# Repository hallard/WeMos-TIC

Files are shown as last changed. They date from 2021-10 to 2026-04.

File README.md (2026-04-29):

# WeMos Teleinfo ESP8266/ESP32/S2/C3/S3 Shield

This shield is used to get French energy meter called Teleinfo data with any of the following boards:

- [WeMos D1 Mini][22] ESP8266
- [MH et Live ESP32 Mini Kit][23]
- [WeMos Mini S2][25] 
- [WeMos Mini C3][26]
- [WeMos Mini S3][27]

Take care the check wiring, because there is a lot of clone boards so please be sure to order the correct ones. If you want to be sure you can add it as option when you order this shield on [tindie][24], in bonus it will be flashed with tasmota teleinfo firmware.

Since price difference between ESP32 and ESP8266 boards is so small, to be able to use all future features such as Tamota with TLS, [Berry language](https://tasmota.github.io/docs/Berry/) or even tasmota new applications, I strongly suggest to use with ESP32 only. In the meanwhilen due to lack of ressources and Serial for debug (when using teleinfo), **no support for ESP8266 will be provided**. Of course it works fine, but I spent too much time each time to reproduce and track issues so I let it behind for now to focus on ESP32.  

**New in v1.2**

- Changed R3 by adjustable 2K resistor (trimer) to adjust Teleinfo signal sensitivity for Standard/Historique modes
- Added QWIIC/STEMA I2C classic connector
- Changed Blue Led resistor to decrease light intensity
- Placed easy cutting trace to disable Teleinfo Blue LED

**v1.1**

- Default RX goes to GPIO13 on ESP8266, GPIO23 on ESP32 (see other below)
- Reduded WS2812 RGB Led size, 4.3V powered, better brigtness 
- Added visual LED on teleinfo receive signal
- Reverted Signal 3V3 and GND on I2C connector, now "standard" looks more like that
- Replaced 2 GND pins by 5V and 3.3V to get more external power pins

**v1.0**

- Teleinfo Reader interface
- I2C Pullups placement
- Footprint for WS2812B RGB LED
- Classic I2C 128x64 OLED or sensors connector
- pad to solder components if needed to

WeMos provide three types of D1, [D1 Mini Lite][20], [D1 Mini][21] or [D1 Mini Pro][22] and also new [MH et Live ESP32 Mini Kit][23]

# Detailed Description

Look at the schematics for more informations, easy to understand. Wiring on the WeMos Teleinfo shield is as follow:

| Pin Function | ESP32 | ESP8266 | ESP32-S2 | ESP32-C3 | ESP32-S3 |
|  :--- |  :---:  |  :---:  |  :---: |  :---: |  :---: |
| Téléinfo Rx  |  GPIO23 | GPIO13  | GPIO11 | GPIO4 | GPIO11 |
| RGB Led |  GPIO18 | GPIO14  | GPIO7 | GPIO2 | GPIO12 |
| I2C SDA |  GPIO21 | GPIO4 | GPIO33 | GPIO8 | GPIO35 |
| I2C SCL |  GPIO22 | GPIO5 | GPIO35 | GPIO10 | GPIO36 |

You can change default Rx to `GPIO3` with solder pad `tic-rx`, but in this case, you need to cut the default trace and put solder between center pad and `IO3`, It's for advanced users, do it only if you need it and if you know what you are doing.

Default wiring on [ESP8266 Mini D1][21], [ESP32 Mini Dev board][23], [ESP32 S2 Mini][25] or [ESP32 C3 Mini][26] or [ESP32 S3 Mini][27]

| Pin Function | ESP32  | ESP8266 | ESP32-S2 | ESP32-C3 | ESP32-S3 |
|  :--- |  :---: |  :---:  |  :---: |  :---: |  :---: |
| On Board LED |  GPIO2 | GPIO16  | GPIO15 |  GPIO7 |  GPIO47  |
| On Board Button |  GPIO0 | GPIO16  |  GPIO0 |  GPIO9 |  GPIO0 |

Note : On ESP32-S3 the On Board LED is RGB WS2812 (same than on this shield) so to drive Shield LED use IO12 and to drive S3 Led use IO47

# Schematics

## V1.2
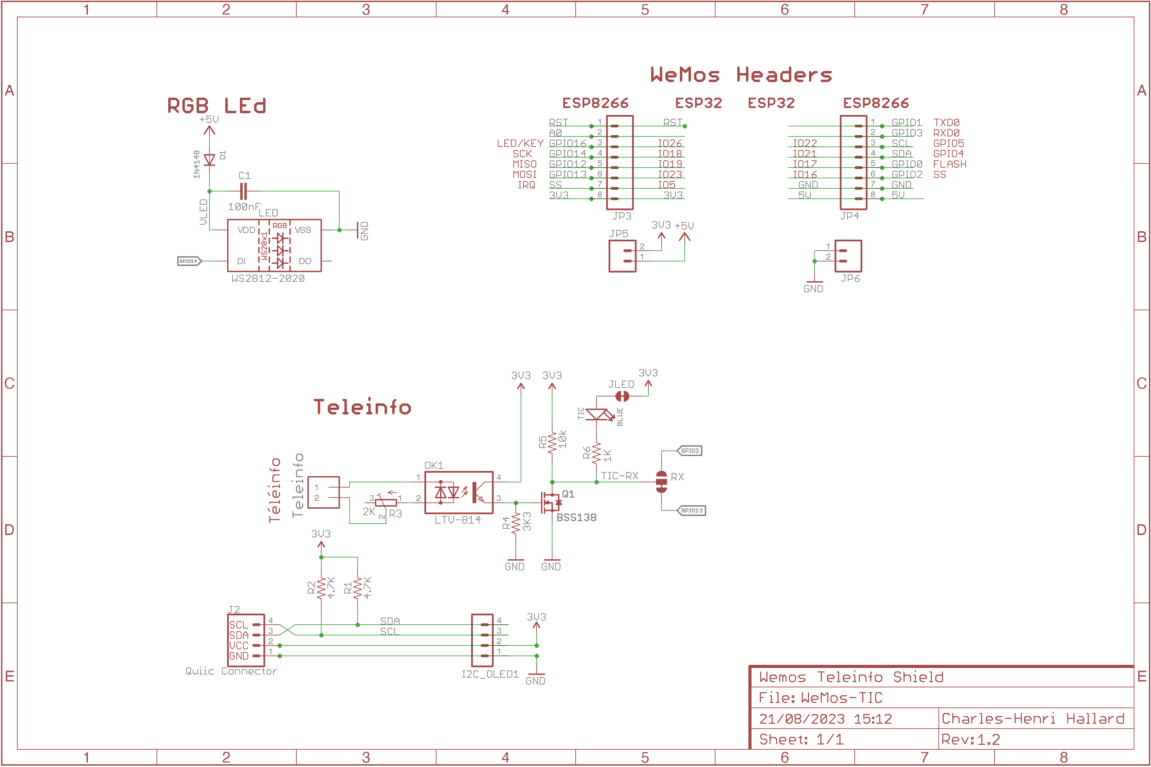
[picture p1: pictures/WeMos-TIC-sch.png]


## V1.1
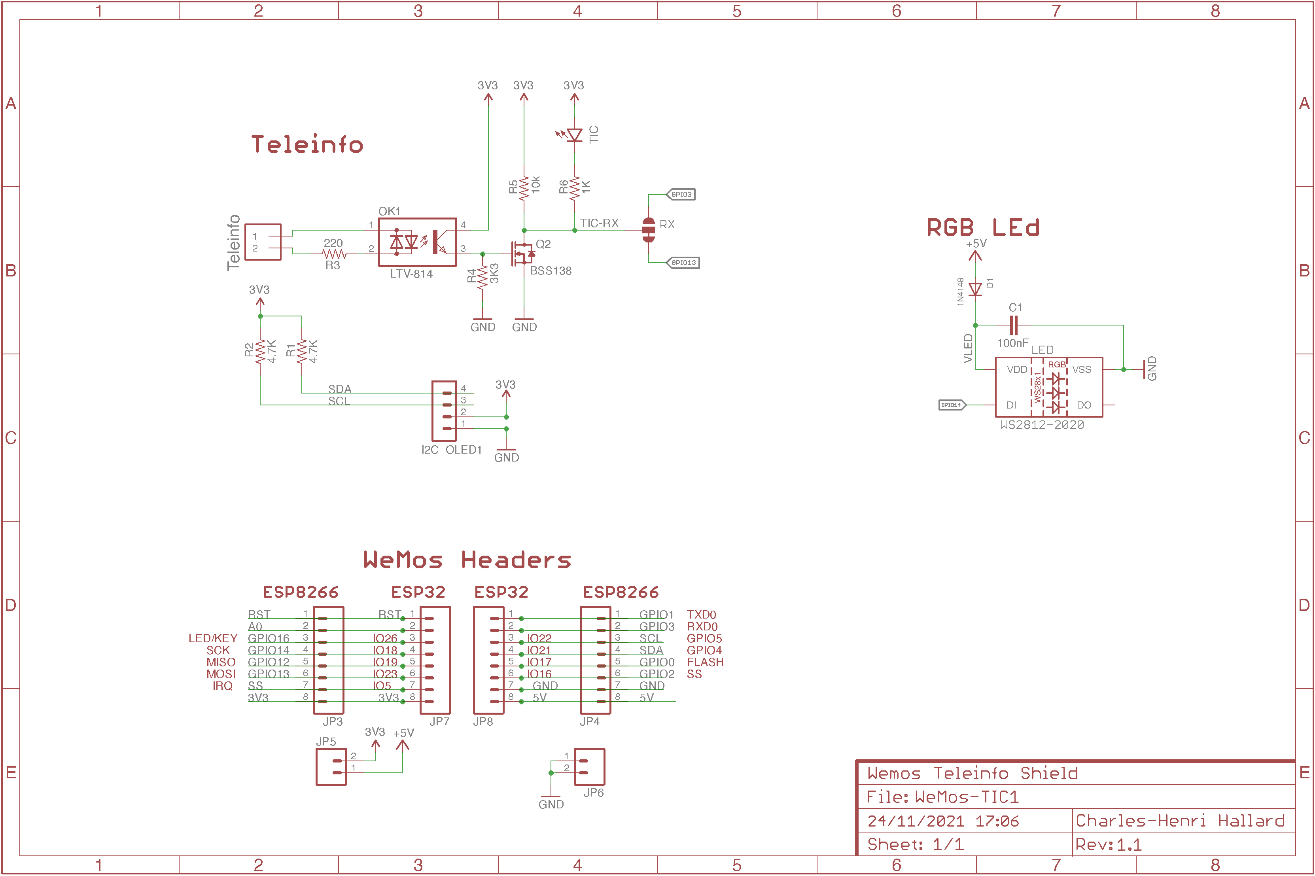
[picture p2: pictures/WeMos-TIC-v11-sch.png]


# Boards (V1.1)

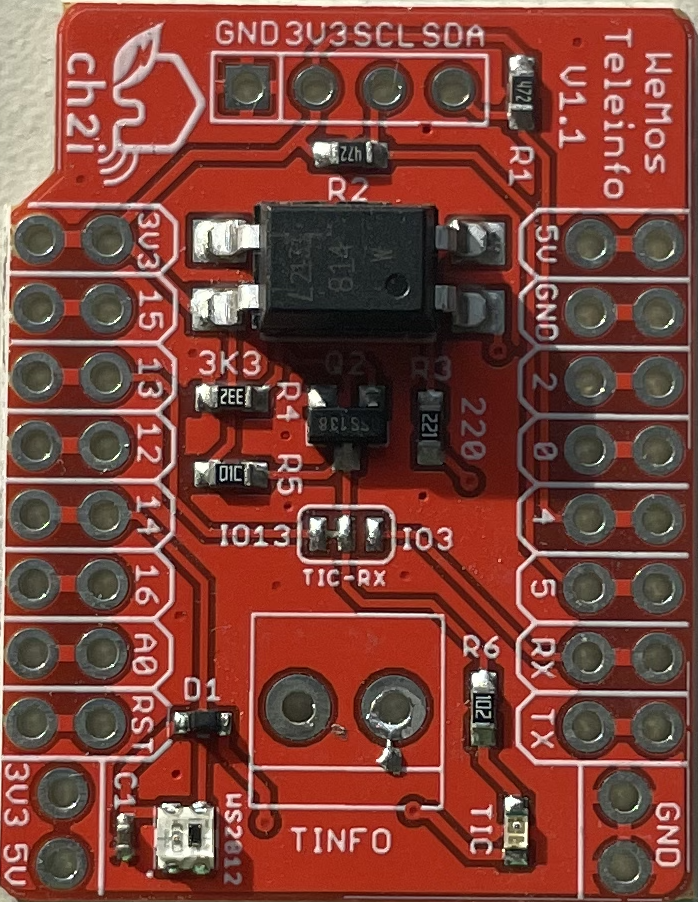
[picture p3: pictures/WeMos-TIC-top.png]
Top
&nbsp;
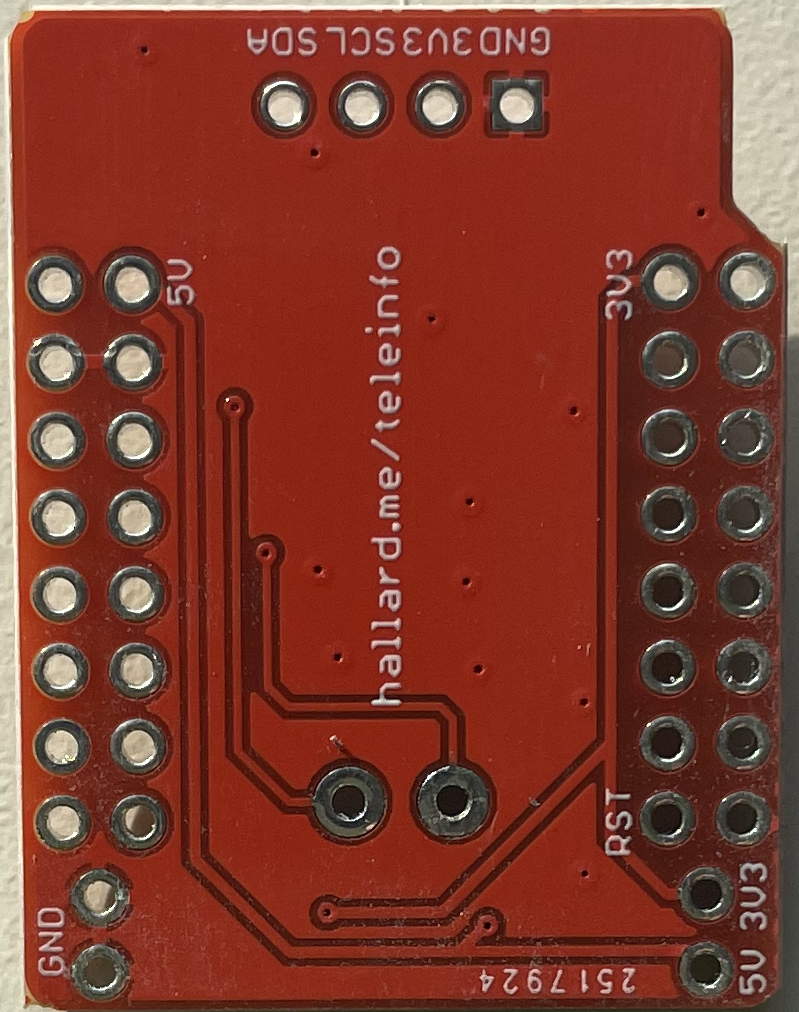
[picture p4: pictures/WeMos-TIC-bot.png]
Bottom


# Assembled boards

Here an example of boards connected with wiring on [ESP32 Mini Dev board][23]

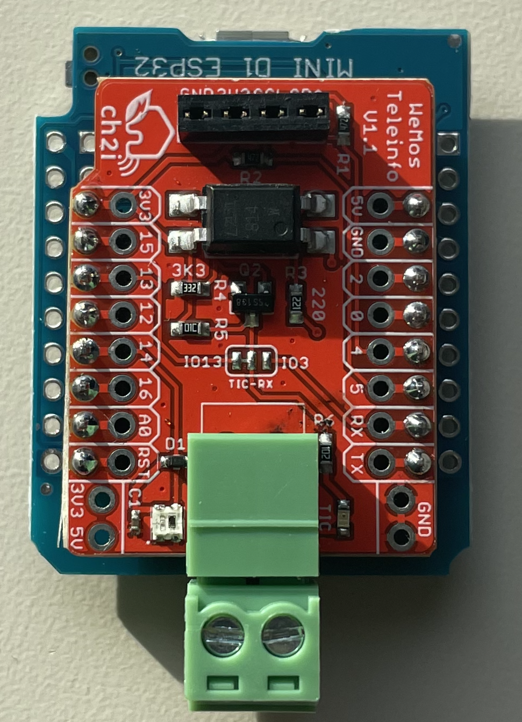
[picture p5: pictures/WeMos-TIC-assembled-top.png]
WeMos Teleinfo Assembled TOP
&nbsp;
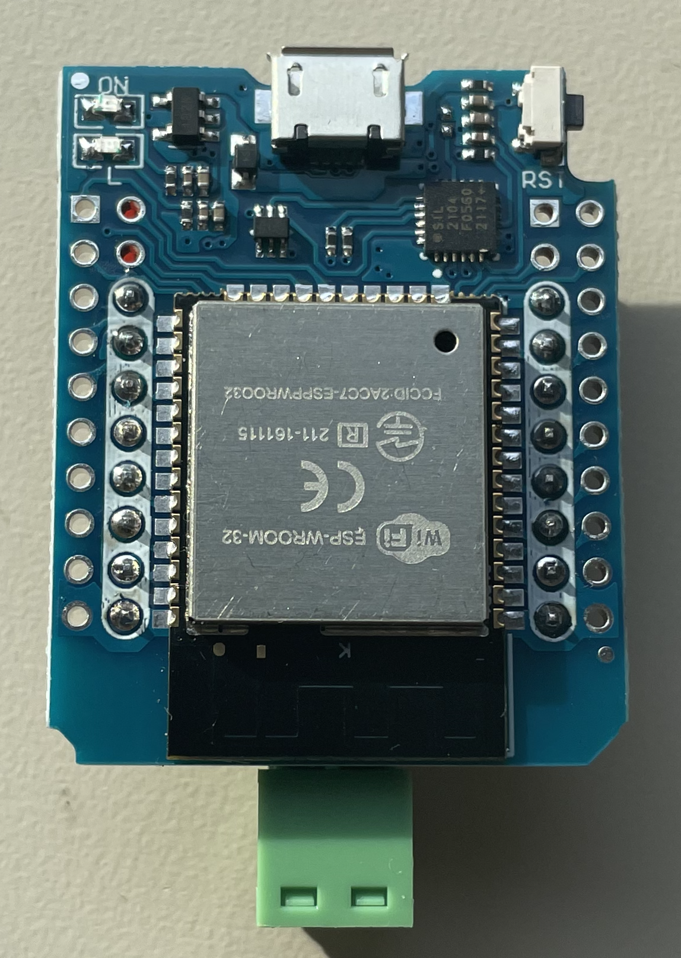
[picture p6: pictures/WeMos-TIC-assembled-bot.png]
WeMos Teleinfo Assembled Bottom


# Assembling

Nothing complicated, just use and solder headers. I suggest to use the small ones I sell with shield on Tindie, takes less place and you can either fix for life with just one part of the header soldered on both shield and ESP32.

Here boards connected to [ESP32 Mini Dev board][23]

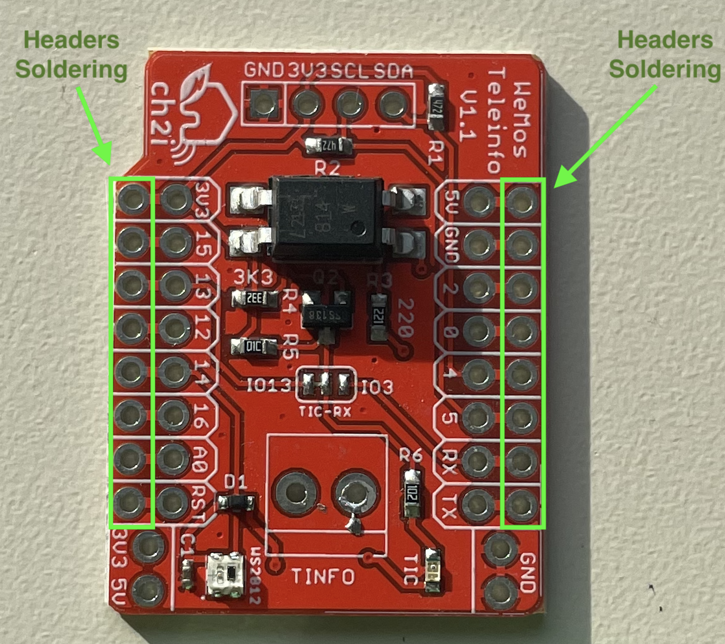
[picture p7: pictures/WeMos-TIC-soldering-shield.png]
&nbsp;
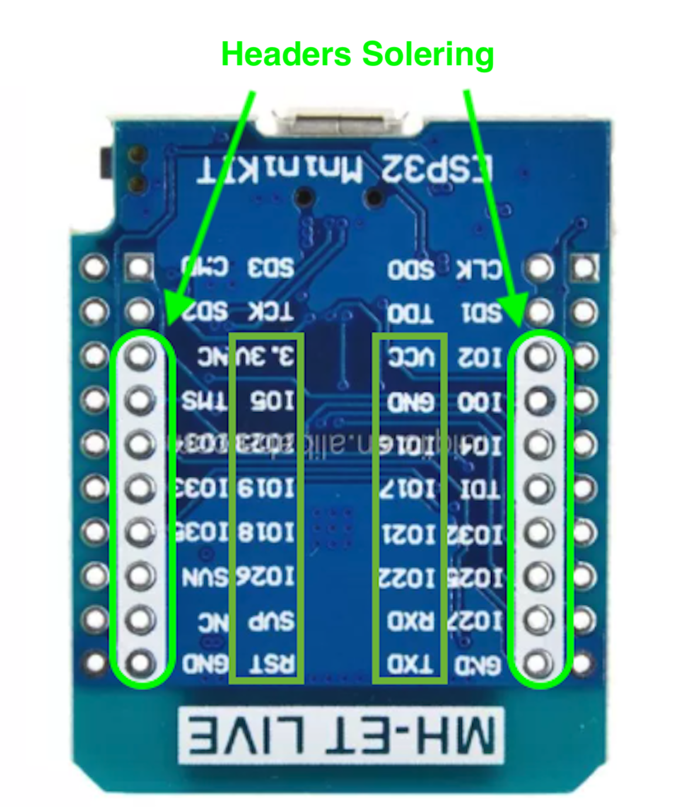
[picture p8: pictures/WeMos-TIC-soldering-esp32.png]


# 3D Print enclosure

@barbudor was kind enough to build and share awesome 3D enclosure for this shield. you can find `stl` file to print your own [here](3dprinted_enclosure). see pictures below

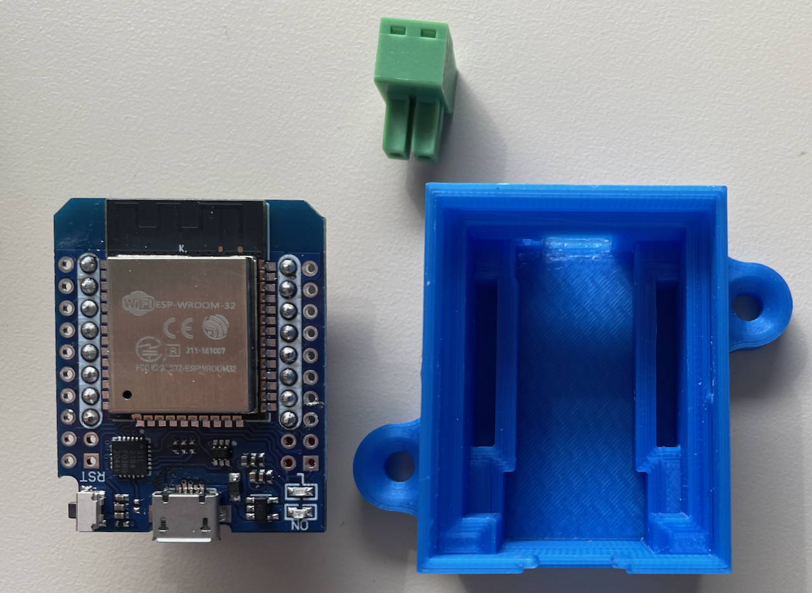
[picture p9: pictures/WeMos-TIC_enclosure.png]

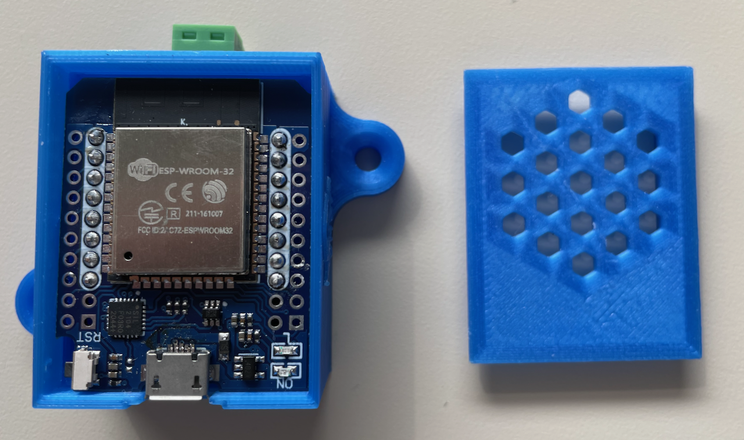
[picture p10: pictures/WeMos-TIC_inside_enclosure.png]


:warning: This enclosure fit perfelctly shield connected with WemMos ESP32 or D1 Mini ESP8266 **only when assembled with small headers**
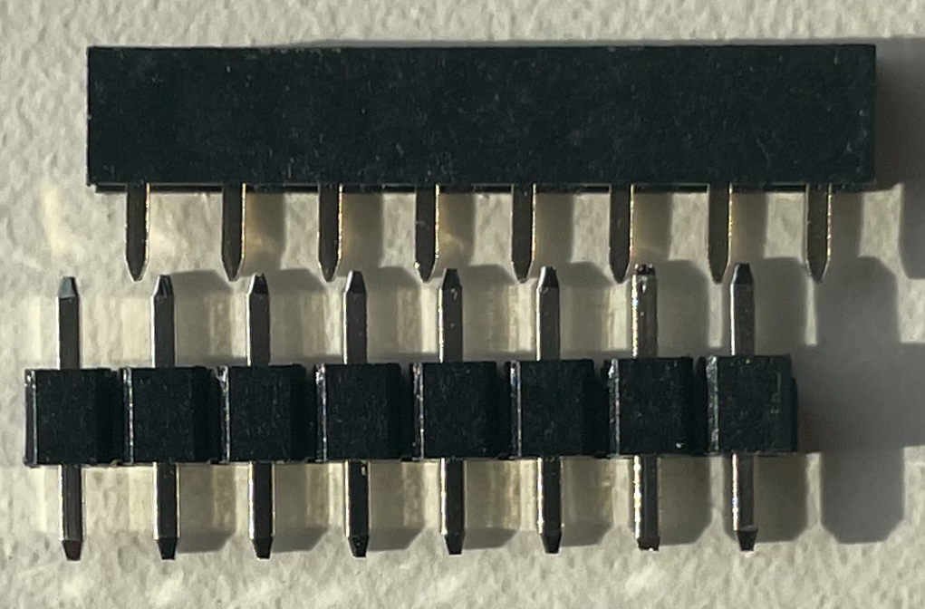
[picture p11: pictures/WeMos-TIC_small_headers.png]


You can add these headers when you order this shield on my [tindie store][24]

# Firmware 

You can write your own and use with [LibTeleinfo](https://github.com/hallard/LibTeleinfo) library I wrote if you want to get rid of driving teleinfo stuff (chekout some [examples](ttps://github.com/hallard/LibTeleinfo/tree/master/examples)).

## Tasmota

But I strongly suggest using amazing [Tasmota](https://tasmota.github.io/docs/) firmware, all is already done and well done.

Please check Teleinfo official tasmota [documentation](https://tasmota.github.io/docs/Teleinfo/) so see how to configure your device depending on smartmeter type and what options you need.

### Nicolas's builds

Nicolas @NicolasBernaerts has made awesome changes on Tasmota to be able to show graph of consumption, history and other great features such has:

- Ecowatt server to publish RTE Ecowatt signals
- TCP server to live stream teleinfo data
- FTP server to easily retrieve graph data

You can find more information on his dedicated [repo](https://github.com/NicolasBernaerts/tasmota/tree/master/teleinfo) and also ready made build for all compatible ESP boards.

### Unofficial builds

Teleinfo is not member of official Tasmota builds. So you need to build your own with `USE_TELEINFO` define. 
But Tasmota team agreed it's not simple to build for end users, and they now provide unofficial build that follow developement branch, this mean you always have an up to date build with latest code available. Of course we added Teleinfo (ESP8266 and ESP32) builds in this unofficial build process so you have nothing to install and compile/link (building). You can't go easier.

And as a cherry on the cake, easy flasher tools (web version and executable one) will present Teleinfo firmware so you are able to flash teleinfo firmware in less than 1 minute. You can check detail [here](https://github.com/Jason2866/Tasmota-specials) but here how to do that.

- Launch [Web Flasher here](https://jason2866.github.io/Tasmota-specials/) 
- Select Teleinfo (flash will auto detect if you need ESP8266 or ESP32 and will flash the correct one)
- Select Serial port, and click `install`

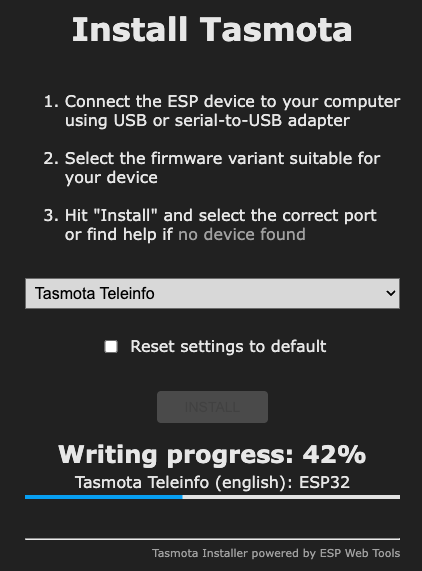
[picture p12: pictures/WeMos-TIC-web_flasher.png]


Once done something like that

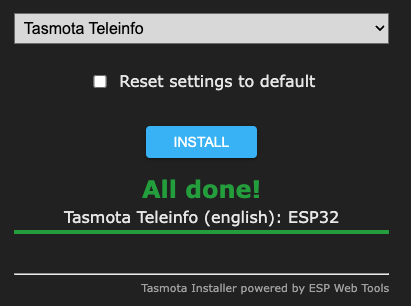
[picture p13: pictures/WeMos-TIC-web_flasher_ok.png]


After flashed, you should now see a new access point named `tasmota_aabbcc_xxxx` where you can connect to configure your WiFi for the device to connect on.

Alternatively, if you connect serial console and reset the device you should see Serial logs like that
```
00:00:00.003 HDW: ESP32-D0WDQ6 
00:00:00.037 UFS: FlashFS mounted with 308 kB free
00:00:00.109 CFG: Loaded from File, Count 12
00:00:00.124 QPC: Count 1
00:00:00.257 CFG: no '*.autoconf' file found
00:00:00.263 BRY: Berry initialized, RAM used=3620
00:00:00.282 BRY: no 'preinit.be'
00:00:00.291 Project tasmota - Tasmota Version 10.0.0.3(teleinfo)-2_0_1_1(2021-11-30T14:22:47)
00:00:00.379 BRY: no 'autoexec.be'
00:00:00.447 WIF: WifiManager active for 3 minutes
00:00:01.139 HTP: Web server active on tasmota-090F8C-3980 with IP address 192.168.4.1
00:00:06.827 QPC: Reset
```

If you want to deep into this process or just curious, you can check out it's [here](https://github.com/Jason2866/Tasmota-specials)

:memo: If you have some issues flashing with Web Flasher, do not hesitate to use another awesome tool [ESP Flasher](https://github.com/Jason2866/ESP_Flasher), with this one you can see exactly what's going on in case of issue because it has built in console. Usefull also after reboot of the device because console still active. This is the one I'm using day by day. In this case you need to download firmware to flash first [here](https://github.com/Jason2866/Tasmota-specials/tree/firmware/firmware/tasmota/other). Download firmware `tasmota-teleinfo`

You can take a look on `autoconf` [folder](https://github.com/tasmota/autoconf/tree/main/raw/esp32/Wemos_Teleinfo) to see some of init commands used on ESP32. For ESP8266 you can copy content of `autoexec.bat` and manually apply to you ESP8266 teleinfo.

:memo: Don't forget to reset Energy counters on first boot with console command `EnergyTotal 0` if you have erratic values. 

### I2C Display

You can add fancy I2C display (or even I2C sensors), take care of wiring of the display. They are not all usin the same order wiring the 4 pins on I2C connector. You need to use one with this order `GND VCC SDL SDA`. Since I2C VCC is conencted to 3.3V, your I2C device is compatible with 3.3V or 5V ones (They all have shifter since majorty of sensors works at 3.3V)

Then with tasmota you need to select correct one, in my example below it's an SHT1106 128x64 so config is (use only one time). Pleasy check Tasmota documentation for [display](https://tasmota.github.io/docs/Displays/) and associaed [commands](https://tasmota.github.io/docs/Commands/#displays).

```
DisplayMode 2
; 2 for SSD1306 and 7 for SH1106
DisplayModel 2
displaycols 21
displayrows 8
```

Don't forget to toggle ON on tasmota WEB UI since it's like a device. If not nothing will be displayed. You can also check the OLED presence using command `i2cScan` from console, something loke below sounds good, seen on `0x3c`

```
13:09:39.490 CMD: i2cscan
13:09:39.531 MQT: stat/tasmota_EF58A0/RESULT = {"I2CScan":"Device(s) found at 0x3c"}
```

And here is a picture of the whole working.

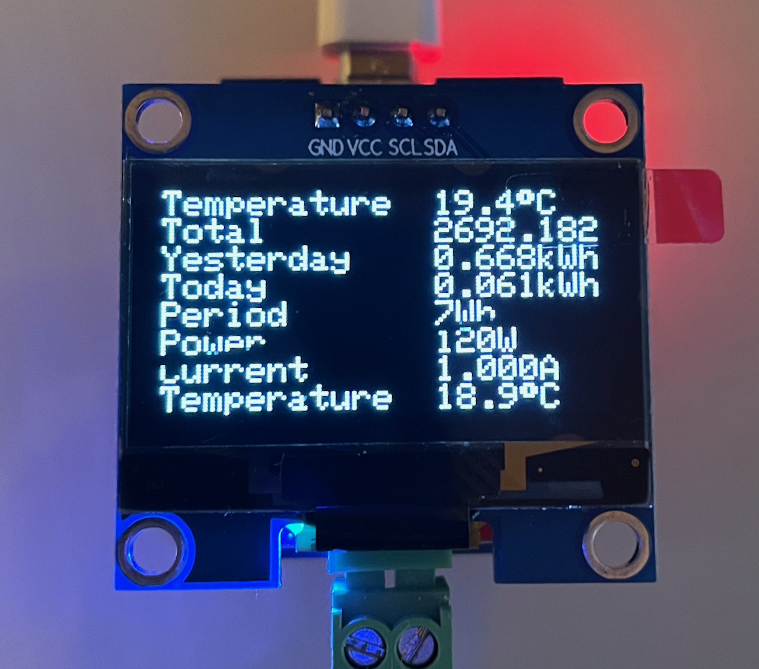
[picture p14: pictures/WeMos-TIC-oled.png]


### Autoconf (ESP32 Only)

Another awesome feature of Tasmota is the ability to download configuration profile, and guess what, we done it for this shield, just go to configuration option, select Autoconfig and then choose in the list `Wemos Teleinfo` and here you are, ne need to copy/paste template, it's done by autoconfig.
If you want to deep into this process or just curious, you can check out it's [here](https://github.com/tasmota/autoconf)

### Berry Scripting (ESP32 Only)

Now you can personalize code with [Berry language](https://tasmota.github.io/docs/Berry/). Check out some Berry samples [here](https://github.com/arendst/Tasmota/blob/development/tasmota/berry/examples/)

You can do that by going to Berry console from Tasmota WEB user interface.

#### Drive RGB LED depending on actual power

Here is a Berry example, goal is to follow real time consumption driving on board RGB Led depending on current Power consumption (low green then going to red when reaching maximum current of your contract)

```python
#-
# example of using Berry script to change the led color
# accordingly to power consumption
# using Denky or WeMos Teleinfo (French Teleinfo reader)
-#

#- define the global symbol for reference -#
runcolor = nil

def runcolor()
  var max_contrat = 30 # contrat 30A
  var i = energy.current
  #print(i)
  var red = tasmota.scale_uint(int(i), 0, max_contrat, 0, 255)
  var green = 255 - red
  var channels = [red, green, 0]
  light.set({"channels":channels, "bri":64, "power":true})
  tasmota.set_timer(2000, runcolor)
end

#- run animation -#
runcolor()
```

#### Send data to Emoncms with Berry (ESP32 only)

What's magic with Berry is the ability to do basic stuff with data, in this example we will intercept MQTT send message by Energy driver, do some calc and send data to Emoncms every 15 seconds and also to drive RGB Led from Green (low load) to Red (approach max subscription)

Modifiy API key with your, and copy paste the following code into Berry Console. Tst and validate if all is okay for you.

Once all is fine, you paste the code into a file named `autoexec.be` on the Tasmota Filesystem so it will be executed each time Tasmota device starting.

### Mode Historique (contrat heures creuses)

```python
import json

var api_url = "https://emoncms.org/input/post"
var api_key = "YOUR_EMON_API_WRITE_KEY"
var node_name = "NODE_NAME"
var post_every = 15000 # post evert 15 seconds
var payload = {}

def send_emoncms()
  # Convert JSON object to string 
  var obj_json = json.dump(payload)

  # Create URL to call
  var param="?fulljson="+obj_json + "&node="+node_name + "&apikey="+api_key 
  # Post Data to EMONCMS
  var cl = webclient()
  cl.begin( api_url + param)
  var r =  cl.GET()
  tasmota.set_timer(post_every, send_emoncms)
end

def setcolor(iinst, isousc)
  var red = tasmota.scale_uint(iinst, 0, isousc, 0, 255)
  var green = 255 - red
  var channels = [red, green, 0]
  light.set({"channels":channels, "bri":64, "power":true})
end

# set global payload the field we need
def rule_tic(value, trigger)
  # Got Heures Creuses contract so I will calculate total consumption
  # adding Heures Creuses (HCHC) + Heures Pleines (HCHP) and create new value for emoncms 
  # Change label depending on name for your contract type
  var htot = value['HCHP'] + value['HCHC'] # mode historique
  # Create new value HTOT converted to kWH
  payload['HTOT'] = htot / 1000.0
  # Calculate current percent Load 
  var iinst = value['IINST']  # mode historique
  var isousc= value['ISOUSC'] # mode historique

  if iinst != nil && isousc != nil 
    # Drive RGB LED
    setcolor(iinst, isousc)
    if isousc > 0
      load = 100 * iinst / isousc
      payload['LOAD'] = load
    end
  end

  # Set values we need to send to emoncms
  payload['ADCO']  = value['ADCO']
  payload['HCHP']  = value['HCHP']
  payload['HCHC']  = value['HCHC']
  payload['ISOUSC']= isousc
  payload['PAPP']  = value['PAPP']
  payload['IINST'] = iinst

end

def start()
  # Callback on each frame interception
  tasmota.add_rule("TIC",rule_tic)
  # fire 1st post in 5s 
  tasmota.set_timer(5000, send_emoncms)
end

# delay start to have time to get full frame
tasmota.set_timer(10000, start)

```

### Mode Standard (contrat heures creuses)

```python
import json

var api_url = "https://emoncms.org/input/post"
var api_key = "YOUR_EMON_API_WRITE_KEY"
var node_name = "NODE_NAME"
var post_every = 15000 # post evert 15 seconds
var payload = {}

def send_emoncms()
  # Convert JSON object to string 
  var obj_json = json.dump(payload)

  # Create URL to call
  var param="?fulljson="+obj_json + "&node="+node_name + "&apikey="+api_key 
  # Post Data to EMONCMS
  var cl = webclient()
  cl.begin( api_url + param)
  var r =  cl.GET()
  tasmota.set_timer(post_every, send_emoncms)
end

def setcolor(iinst, isousc)
  var red = tasmota.scale_uint(iinst, 0, isousc, 0, 255)
  var green = 255 - red
  var channels = [red, green, 0]
  light.set({"channels":channels, "bri":64, "power":true})
end

# set global payload the field we need
def rule_tic(value, trigger)
  # Got Heures Creuses contract so I will calculate total consumption
  # Calculate current percent Load 
  var iinst = value['IRMS1']  
  var isousc= value['PREF']*5 

  if iinst != nil && isousc != nil 
    # Drive RGB LED
    setcolor(iinst, isousc)
    if isousc > 0
      load = 100 * iinst / isousc
      payload['LOAD'] = load
    end
  end

  # Here I keep name of historique mode
  payload['ADCO']  = value['ADSC']
  payload['HTOT']  = value['EAST'] / 1000 # I need kWh
  payload['HCHP']  = value['EASF01']
  payload['HCHC']  = value['EASF02']
  payload['ISOUSC']= isousc
  payload['PAPP']  = value['SINSTS']
  payload['IINST'] = iinst

end

def start()
  # Callback on each frame interception
  tasmota.add_rule("TIC",rule_tic)
  # fire 1st post in 5s 
  tasmota.set_timer(5000, send_emoncms)
end

# delay start to have time to get full frame
tasmota.set_timer(10000, start)

```

### Tasmota templates

Use the following templates depending on version of shield and ESP board (but I strongly suggest using autoconf if you have a ESP32 board)

#### Shield Version 1.1

ESP8266
```
{"NAME":"Wemos Teleinfo","GPIO":[1,1,1,1,640,608,1,1,1,5152,1376,1,1,1],"FLAG":0,"BASE":18}
```

ESP32
```
{"NAME":"Wemos Teleinfo","GPIO":[1,1,1,1,1,1,1,1,1,1,1,1,1,1,1376,1,1,640,608,5632,1,1,0,1,0,0,0,1,1,1,1,1,1,1,1,1],"FLAG":0,"BASE":1}
```

ESP32-S2-Mini
```
{"NAME":"Wemos Teleinfo","GPIO":[1,1,1,1,1,1,1,1376,1,1,1,5632,1,1,1,1,1,1,1,5632,1,1,640,1,608,1,0,1,1,1,1,1,1,1,1,1],"FLAG":0,"BASE":1}
```

ESP32-C3-Mini
```
{"NAME":"Wemos Teleinfo","GPIO":[1,1,1376,1,5632,1,1,288,640,1,608,1,1,1,1376,1,1,640,1,0,1,1],"FLAG":0,"BASE":1}
```

ESP32-S3-Mini
```
{"NAME":"Wemos Teleinfo","GPIO":[32,1,1,0,0,1,1,1,1,1,1,5632,1376,1,0,1,1,1,1,1,1,1,0,0,640,608,0,0,0,0,0,0,1,1,0,0,1377,0],"FLAG":0,"BASE":1}
```

#### Shield Version 1.0

Teleinfo RX is on GPIO3 for each board

ESP8266
```
{"NAME":"TICShield","GPIO":[1,1,1,5152,640,608,1,1,1,1,1376,1,1,1],"FLAG":0,"BASE":18}
```

ESP32
```
{"NAME":"TICShield32","GPIO":[1,1,1,5632,1,1,1,1,1,1,1,1,1,1,1376,1,1,640,608,1,1,1,0,1,0,0,0,1,1,1,1,1,1,1,1,1],"FLAG":0,"BASE":1}
```

# Support and discussion

If you have any issue or just want to discuss on this project, please use community [forum](https://community.ch2i.eu/category/19/wemos-teleinfo)

# License

   

This work is licensed under a [Creative Commons Attribution-NonCommercial-ShareAlike 4.0 International License](https://creativecommons.org/licenses/by-nc-sa/4.0/)    
If you want to do commercial stuff with this project, please contact [CH2i company](https://ch2i.eu/en#support) so we can organize an simple agreement.

# Lazy building your own? 

You can order this shield fully assembled with some extra on [tindie][24] or on [Lectronz](https://lectronz.com/products/wemos-tic).

European customers may prefer ordering on Lectronz, which offers additional payment methods and pricing in Euros.





# Misc

See news and other projects on my [blog][2] 
 
[2]: https://hallard.me

[20]: https://www.wemos.cc/en/latest/d1/d1_mini_lite.html
[21]: https://www.wemos.cc/en/latest/d1/d1_mini.html
[22]: https://www.smart-prototyping.com/Mini-D1-PRO-Development-Board-ESP8266-4M-16M
[23]: https://www.az-delivery.de/fr/products/esp32-d1-mini
[24]: https://www.tindie.com/products/25467/
[25]: https://www.wemos.cc/en/latest/s2/s2_mini.html
[26]: https://www.wemos.cc/en/latest/c3/c3_mini.html
[27]: https://www.wemos.cc/en/latest/s3/s3_mini.html

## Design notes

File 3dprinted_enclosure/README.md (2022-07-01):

# 3D Printed Enclosure for WeMos-TIC
by Barbudor
Designed with TinkerCAD

v1.1 : available here https://www.tinkercad.com/things/gjrSG7AgKoE-mini-d1-esp32-teleinfo-v11

Tested with mini-D1 ESP32 and D1 Mini ESP8266.

:warning: This enclosure perfectly fits Teleinfo shield mounted below a WeMos ESP32 or D1 Mini ESP8266 **only when assembled with small headers**


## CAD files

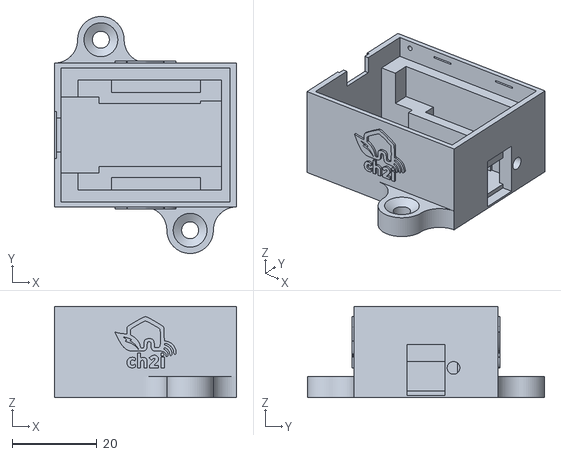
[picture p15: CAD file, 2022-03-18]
3dprinted_enclosure/enclosure.stl
43.0 x 56.0 x 21.5

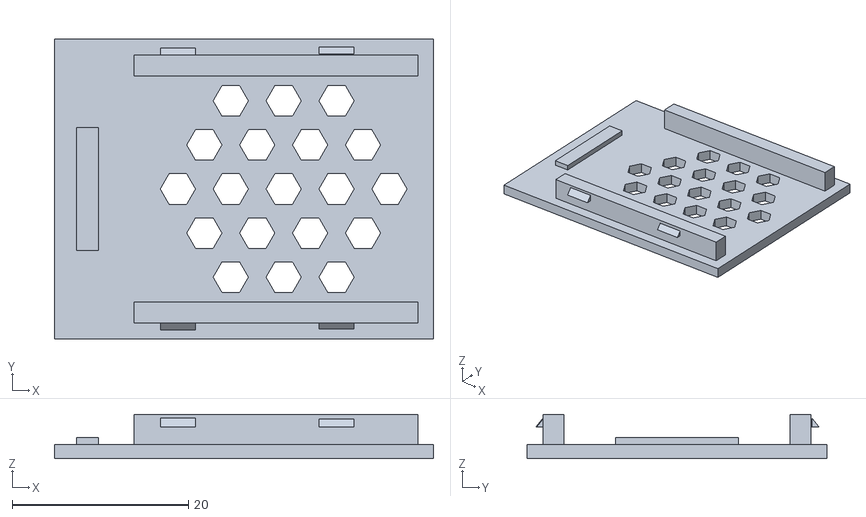
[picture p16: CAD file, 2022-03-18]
3dprinted_enclosure/lid.stl
43.0 x 34.0 x 5.00

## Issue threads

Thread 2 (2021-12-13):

Erreur N° GPIO

remycrochon, 2021-12-13:
Bonjour
Dans le tableau le numéro de pin du RX du ESP32 est GPIO23 et non GPIO32
Salutations

hallard, 2021-12-14:
Correct, merci du retour c'est fixé

Closed 2021-12-14.

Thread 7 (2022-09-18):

soldering schema for WeMos Mini S2 ?

mcarbonneaux, 2022-09-18:
I've buy your shield and i whant to be sure how to connect it.

How to solder your adapter to the mini s2 ? use external or internal line ?
You have made the schematique for the esp32 mini dev, but not for the other one...

her : https://github.com/hallard/WeMos-TIC#assembling
When see you table her : https://github.com/hallard/WeMos-TIC#detailed-description

If I understand all pine of your shield are linked for each couple of external/internal line.

If i sold the exterior line of your shield to the external line of S2 like that :

| Shield Pin | ESP32-S2 |
|  :---        |    :---:   |
| GND  | GND |
| 5V | VBUS |
| 3V3 | 3V3 |

And normaly the pin function table while be :

| Shield Pin Function | ESP32-S2 |
|  :---        |    :---:   |
| Téléinfo Rx  | <**GPIO37**> |
| RGB Led (14)     | GPIO07 |
| I2C SDA (4)     | GPIO33 |
| I2C SDL  (5)    | GPIO35 |

LED/SDA/SDL are corresponding but RX are not corresponding to the GPIO of your table (GPIO11 in your table and GPIO37 on the corresponding pin on S2).

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

hallard, 2022-09-20:
If you look at the schematic of the shield (which is the same for all module), Teleinfo RX is connected to `GPIO13` (to leave RX/TX is for serial console) so it's `GPIO11` on S2 and all magic match :-)

Blank text on the PCB (silk) is the one for ESP8266 that may, I must admit do some confusion, but that's the price of compatibility and this is why I put mapping table on the readme.

mcarbonneaux, 2022-09-21:
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&nbsp;
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&nbsp;
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&nbsp;
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&nbsp;

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

hallard, 2022-09-21:
Thanks for sharing

Closed 2022-09-20.

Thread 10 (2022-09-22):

Le total energy est negatif

maelremrem, 2022-09-22:
Apres avoir attendu 24h,
Le total energy est négatif
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
J'ai aussi un soucis coté remontée d'info sur HomeAssistant, je peux remonter que le total énergétique et pas la consommation du jour
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
J'ai bien basculé en mode standard car j'ai un linky
Si vous avez des pistes
(Merci pour le PCB, vraiment super propre mais il ne rentre pas dans le STL fourni si on utilise un écran oled, je vais redesign un modèle 3D pour ça)

hallard, 2023-02-27:
peut-on clôturer cette issue ?

Closed 2024-01-11.

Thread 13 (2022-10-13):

Is is suitable for running on battery? (Wemos S2)

Donokami, 2022-10-13:
Hey,
And thanks for the project.
Before buying a WeMos-TIC shield, I was asking myself : what is the power consumption of the ESP32 with the WeMos-TIC board and the project running?
Would it be suitable for running the ESP on a battery? I don't have a modular socket on my electric panel, nor any socket around it :/

hallard, 2022-10-28:
Interesting I did not measured but since it does not sleep and has WiFi at least 100mA so depending on battery capacity should not go above few days.

Closed 2023-02-27.

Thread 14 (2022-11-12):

Portage vers Micropython

mdaeron, 2022-11-12:
Bonjour, merci pour ce projet !

Je suis un grand fan du Wemos S2 Mini que j'utilise sous Micropython pour pas mal de projets. J'aimerais acheter ce module et écrire moi-même (sous license libre évidemment) le code permettant de lire/sauvegarder/transmettre les valeurs de consommation. J'ai un peu regardé ici mais pour je n'ai pas encore compris si le code "habituel" (Tasmota Téléinfo ?) est open-source, et si oui où on peut le trouver.

hallard, 2022-11-12:
Le mieux (et le plus simple) et peut être de prendre le code de la librairie [LibTeleinfo](https://github.com/hallard/LibTeleinfo) (celle ci est incluse dans tasmota)

mdaeron, 2022-11-12:
Merci ! Du coup je viens d'en commander un sur Tindie. Beau projet bien ficelé, merci aussi pour les infos sur le blog.

Closed 2022-11-12.

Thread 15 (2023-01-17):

Wemos-Teleinfo & ESPHome: "bad crc" and "no group found" errors

tomav, 2023-01-17:
Hi @hallard, thanks for the wemos teleinfo board, I got mine from Tindie.
It works but I got these errors:

```
[23:12:12][E][teleinfo:133]: No group found
[23:12:16][D][sensor:127]: 'WiFi Signal dB': Sending state -61.00000 dBm with 0 decimals of accuracy
[23:12:43][E][teleinfo:038]: bad crc: got 60 except 56
[23:12:43][E][teleinfo:038]: bad crc: got 60 except 50
[23:12:43][D][sensor:127]: 'Linky Index': Sending state 35917.92578 kWh with 0 decimals of accuracy
[23:12:43][E][teleinfo:038]: bad crc: got 34 except 41
[23:12:43][E][teleinfo:168]: Invalid value for tag EASF02
[23:12:43][E][teleinfo:038]: bad crc: got 41 except 72
[23:12:43][E][teleinfo:038]: bad crc: got 41 except 35
[23:12:43][E][teleinfo:038]: bad crc: got 32 except 88
[23:12:43][E][teleinfo:038]: bad crc: got 32 except 95
[23:12:43][D][sensor:127]: 'Linky Puissance Souscrite': Sending state 12000.00000 VA with 0 decimals of accuracy
[23:12:43][D][sensor:127]: 'Linky Puissance Apparente': Sending state 2466.00000 VA with 0 decimals of accuracy
[23:12:43][E][teleinfo:038]: bad crc: got 94 except 84
[23:12:43][E][teleinfo:038]: bad crc: got 24 except 77
[23:12:43][E][teleinfo:038]: bad crc: got 60 except 86
[23:12:43][E][teleinfo:038]: bad crc: got 57 except 32
[23:12:55][D][sensor:127]: 'Uptime': Sending state 1532.19702 s with 0 decimals of accuracy
[23:13:16][D][sensor:127]: 'WiFi Signal dB': Sending state -61.00000 dBm with 0 decimals of accuracy
[23:13:43][E][teleinfo:038]: bad crc: got 60 except 87
[23:13:43][D][sensor:127]: 'Linky Index': Sending state 35917.97656 kWh with 0 decimals of accuracy
[23:13:43][E][teleinfo:038]: bad crc: got 36 except 57
[23:13:43][E][teleinfo:038]: bad crc: got 36 except 95
[23:13:43][E][teleinfo:038]: bad crc: got 41 except 77
[23:13:43][E][teleinfo:038]: bad crc: got 41 except 40
[23:13:43][E][teleinfo:038]: bad crc: got 32 except 87
[23:13:43][E][teleinfo:038]: bad crc: got 32 except 33
[23:13:43][D][sensor:127]: 'Linky Puissance Apparente': Sending state 2957.00000 VA with 0 decimals of accuracy
[23:13:43][E][teleinfo:038]: bad crc: got 94 except 89
[23:13:43][E][teleinfo:038]: bad crc: got 94 except 49
[23:13:55][D][sensor:127]: 'Uptime': Sending state 1592.19702 s with 0 decimals of accuracy
```

Same in historical or standard mode.
I use ESPHome, with an ESP32 (lolin s2 mini).

Here's my config, nothing too fancy.

```
uart:
  id: uart_a
  rx_pin: GPIO11
  baud_rate: 9600 # historical => 1200 / standard => 9600
  parity: EVEN
  data_bits: 7

teleinfo:
  id: myteleinfo
  uart_id: uart_a
  update_interval: 30s
  historical_mode: false # set to false when standard mode enabled

#### STANDARD

 # Energie Active soutirée totale
  - platform: teleinfo
    id: hc_hp
    tag_name: "EAST"
    name: "Linky Index"
    unit_of_measurement: "kWh"
    icon: mdi:flash
    teleinfo_id: myteleinfo
    device_class: "energy"
    state_class: "total_increasing"
    filters:
      - filter_out: 0.0
      - lambda: |-
          return x/1000;

 # Puissance apparente de coupure
  - platform: teleinfo
    id: pcoup
    tag_name: "PCOUP"
    name: "Linky Puissance Souscrite"
    unit_of_measurement: "VA"
    icon: mdi:flash
    teleinfo_id: myteleinfo
    filters:
      - filter_out: 0.0
      - lambda: |-
          return x*1000;

# Puissance apparente instantanée ph1
  - platform: teleinfo
    id: papp
    tag_name: "SINSTS"
    name: "Linky Puissance Apparente"
    unit_of_measurement: "VA"
    device_class: "power"
    state_class: "measurement"
    icon: mdi:flash
    teleinfo_id: myteleinfo

# Tension moyenne ph1
  - platform: teleinfo
    id: umoy1
    tag_name: "UMOY1"
    name: "Linky Umoy"
    unit_of_measurement: "V"
    icon: mdi:flash
    teleinfo_id: myteleinfo

# Courant efficace ph1
  - platform: teleinfo
    id: iinst
    tag_name: "IRMS1"
    name: "Linky Intensité"
    unit_of_measurement: "A"
    icon: mdi:flash
    teleinfo_id: myteleinfo

#### / STANDARD
```

Any idea of what could be the issue?
Any way to check if it's the teleinfo esphome module or the hardware?
Same kind of errors were observed here: https://github.com/esphome/issues/issues/2060#issuecomment-882589485

Thanks for your help!

yannpub, 2023-01-18:
I am running on an esp8266, you can have a look at my config here: https://community.ch2i.eu/topic/1369/wemos-teleinfo-et-esp-home.
it will require small adjustment for esp32, but from what I've read in the past, issues can occur with the uart bus, or the GPIO you chose.

hallard, 2023-02-27:
You can check hardware with some examples of [LibTeleinfo](https://github.com/hallard/LibTeleinfo/tree/master/examples) such as passthru or stats.

harrygr, 2024-03-04:
@tomav did you ever solve this? I have a very similar setup to you (Board off Tindie, ESP32 S2 mini), but my Linky is Historical mode. I'm getting the same errors:

```
[E][teleinfo:038]: bad crc: got 72 except 32
[E][teleinfo:038]: bad crc: got 44 except 60
```

tomav, 2024-03-11:
Hi @harrygr, sadly nope, so I moved quickly to https://github.com/fairecasoimeme/Zlinky_TIC
Works great with MQTT, and nice form factor, no need of an external 5v.

harrygr, 2024-03-12:
@tomav thanks for the response. I did get it working in the end, albeit with still a few `bad crc` errors. However the metrics I'm interested in are getting recorded and injested by HomeAssistant.

Turns out I had to carefully read the [Teleinfo datasheet](https://www.enedis.fr/media/2035/download) to figure out which tag names work for my Linky setup. I ended up with the following (for single-phase, single rate, historical):

```
sensor:
  - platform: teleinfo
    tag_name: "BASE"
    name: "Usage"
    device_class: energy
    unit_of_measurement: "kWh"
    state_class: "total_increasing"
    accuracy_decimals: 3
    icon: mdi:gauge
    filters:
      - multiply: 0.001
      - median:
          window_size: 5
          send_every: 4
    teleinfo_id: linky
  - platform: teleinfo
    tag_name: "IINST"
    name: "Current"
    unit_of_measurement: "A"
    icon: mdi:current-ac
    teleinfo_id: linky
  - platform: teleinfo
    tag_name: "PAPP"
    name: "Apparant Power"
    unit_of_measurement: "VA"
    icon: mdi:flash
    teleinfo_id: linky
```

Closed 2023-02-27.

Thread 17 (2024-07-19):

Niveau de signal insuffisant

Gixy31, 2024-07-19:
Bonjour,
Je viens de recevoir ma carte Wemos TeleInfo, et une fois mise en place j'ai le souci suivant:
Mon oscilloscope décode parfaitement les trames à la sortie de la carte, mais pas mon ESP32. Après avoir vérifié mon soft, j'ai vu surf l'oscillo que le signal de sortie faisait à peine plus de 1V, ce qui explique que l'ESP ne le voit pas. Pour confirmer, j'ai amplifié le signal de sortie avec un transistor et là tout va bien (en passant en mode inverse à cause du transistor), j'ai bien du 3,3V d'amplitude.
Je suspecte que c'est le MOSFET qui est défectueux, qu'en pensez-vous ?

hallard, 2024-07-19:
Bonjour,

Quel type de compteur, quel mode de la téléinfo ? si Linky Standard avez vous essayé de bouger le petit potentiomètre de réglage de sensibilité ?

Gixy31, 2024-07-19:
Bravo pour la réactivité !
Oui, Linky en mode historique. Le potentiomètre ne fait que changer la "propreté" du signal, pas son amplitude, ce qui est normal justement avec l'isolation galvanique. Au début je suspectais un pont diviseur parasite avec la diode bleue, mais il ne peut pas y avoir de courant inverse donc ce n'est pas ça. Si le MOSFET reste un peu passant en permanence, cela peut expliquer le problème. En déconnectant la sortie et la TIC, je devrai avoir 0V sur la gate et 3,3V en sortie, et en réalité j'ai 0,22V sur la gate et 1,14V sur la sortie, donc le MOSFET conduit alors qu'il ne devrait pas.

En tous cas la bibliothèque marche super une fois le signal correct, et elle est très proprement faite (je suis connaisseur...).

hallard, 2024-07-19:
Possible que ce soit le mosfet (ou une mauvaise soudure sur une de ses pattes) mais c'est la 1ere fois que ça arrive.

Je peux vous envoyer un mosfet si vous voulez tenter la chose ou sinon je vous change la carte ?

Merci, c'est vrai qu'elle date cette librairie mais j'ai effectivement essayé de faire propre à l'époque :-)

Gixy31, 2024-07-19:
Je vais regarder les soudures au binoculaire et je vous recontacte. J'ai ce qu'il faut pour dessouder/ressouder, on va essayer de faire au mieux pour éviter le retour de la carte.

hallard, 2024-07-19:
ok, je pense que n'importe quel FET N fera l'affaire

Gixy31, 2024-07-19:
La soudure de la broche source, placée sur un via à la masse était suspecte. J'ai refais les trois et le seul changement est qu'au lieu de 0,2V sur la gate, j'ai maintenant 0,3V et toujours 1,16V en sortie, donc toujours pas glop. Je trouve aussi la soudure de la LED bleue pas terrible, elle aussi avec un via sur un pad. Je mesure 10k dans les deux sens à ses bornes, ce qui n'est pas normal. J'aurais donc tendance à préférer une autre carte car ce n'est peut-être pas le MOSFET. Si je dois te la renvoyer, il faut que je dessoude les barrettes avant.

hallard, 2024-07-19:
Non tu peux laisser les barrettes en revanche je la testerais ici aussi pour voir :-)

En revanche je comprends pas y'a pas de via autours de la led bleu je viens de vérifier tu aurais une photo HD a mettre ?

Gixy31, 2024-07-19:
Exact, c'était une impression. Mais à y regarder de près, cette LED est plus collée que soudée, elle n'est pas d'aplomb, avec deux gouttes de soudure pas étalée en dessous. Problème, je ne peux plus couper la trace qui l'inhibe, puisqu'elle est sous le connecteur :-(

Gixy31, 2024-07-19:
Et pour les 11k constaté aux bornes, c'est normal, on passe par le 3,3V et on fait le tour par R5 et R6...

Gixy31, 2024-07-19:
En revanche, tout débranché, j'ai 4,7k entre drain et source, dans les deux sens, pas normal ça.

Gixy31, 2024-07-23:
Hello,
Sommes nous restés entendus sur le fait que tu m'envoies un MOSFET ?
L'appli est fonctionnelle, j'ai toutes les infos sur Grafana, reste à peaufiner les notifications, display local, etc.

hallard, 2024-07-23:
Yes, tu peux me donner ton numéro de commande Tindie, je t'envois à la même adresse (si d'ici 10min ça part today)

Gixy31, 2024-08-01:
Hello,
N'ayant toujours rien reçu, j'ai fini par cannibaliser un MOSFET sur une vieille carte qui trainait par là et hop, ça marche, c'était  donc bien le MOSFET qui dysfonctionnait. Les données captées par un ESP32, transmises à mon broker MQTT puis à ma base InfluxDB et enfin affichées dans Grafana. Ça donne ceci :
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

hallard, 2024-08-02:
Top, merci pour le retour, j'attendais ton numéro d'order tindie pour retrouver ton adresse pour t'envoyer le mosfet (offre tjs valable bien sur)

Gixy31, 2024-08-02:
J'avais envoyé le n° de commande en répondant au mail, manifestement ça n'est pas passé. Ça marche comme ça, donc ce n'est plus la peine, merci.

Closed 2025-01-08.

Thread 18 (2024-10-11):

choix de la board

sinclairfr, 2024-10-11:
Bonjour à tous,
Doit-on s'attendre une différence significative en termes de "performance" selon si on choisit ESP8266 ou ESP32 ?
Il me semble qu'un ESP8266 est largement suffisant mais je préfère demander avant de souder la board.
Merci !

hallard, 2024-10-11:
Le jour et la nuit, ne serait-ce que

- pour la console série impossible (ou du moins compliqué) avec le 8266 car un seul port série
- MQTT over TLS (pas assez de RAM)
- Pouvoir faire du Berry avec Tasmota
- Vitesse, RAM, ...
- plus d'IO
- support du micropython
- Et j'en passe

En plus c'est quasiment le même prix, aucune hésitation

sinclairfr, 2024-10-12:
Effectivement, c'est le même prix et j'ai les deux donc va pour le ESP32. Merci !

Closed 2025-01-08.

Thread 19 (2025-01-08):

WeMos-TIC + Tasmota : Bug depuis passage en mode standard

ronan-fontenay, 2025-01-08:
Bonjour,

**1 - Matériel**
- Wemos D1 ESP8266
- Wemos Teleinfo v1.2.
-
**2 - Logiciel**
Tasmota 14.4.1.1 (compilé avec la Teleinfo).

**3 - Mode Historique **
Parfait fonctionnement.

**4 - Mode Standard **
Demande à Enedis de passer en mode standard, depuis impossible d'avoir un module qui fonctionne.

Etapes réalisées et problèmes constatés :

1 - Reset Tasmota (pour partir d'un état initial) : OK

2 - Configuration au Wifi : OK

3 - Template : OK
{"NAME":"Wemos Teleinfo","GPIO":[1,1,1,1,640,608,1,1,1,5152,1376,1,1,1],"FLAG":0,"BASE":18}
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

4 - Reboot : OK
Pas d'info car Linky en standard et Tasmota en Historique, a ce stade tout semble OK.
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
A ce stade, voici la configuration :
16:14:40.626 CMD: EnergyConfig
16:14:40.630 TIC: Settings Mode:historique, RX:GPIO13, EN:None, Raw:noraw, Skip:0, Limit:0, Stats:0
16:14:40.633 RSL: RESULT = {"EnergyConfig":"Done"}

5 - Configuration en "standard
16:15:23.921 CMD: EnergyConfig Standard
16:15:23.925 TIC: 'standard' mode
16:15:23.926 TIC: RX on GPIO13, baudrate 9600
16:15:23.936 SNS: Hardware Serial
16:15:23.937 TIC: using hardware serial
16:15:23.940 RSL: RESULT = {"EnergyConfig":"Done"}

Et là, après reboot c'est la cata :
Page principale :
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
Configuration perdue :
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
16:18:17.613 CMD: energyconfig
16:18:17.619 RSL: RESULT = {"Command":"Unknown","Input":"ENERGYCONFIG"}

ronan-fontenay, 2025-01-08:
Bonjour,
Merci pour cette réponse rapide !
Je viens d'essayer sans succès.

J'ai branché la D1 sur le PC, et après activation du template, j'ai l'impression qu'elle redémarre plusieurs fois.
`00:00:00.001 HDW: ESP8266EX
00:00:00.050 CFG: Loaded from flash at F7, Count 37

00:00:00.001 HDW: ESP8266EX
00:00:00.050 CFG: Loaded from flash at F7, Count 37

00:00:00.001 HDW: ESP8266EX
00:00:00.050 CFG: Loaded from flash at F7, Count 37

00:00:00.001 HDW: ESP8266EX
00:00:00.050 CFG: Loaded from flash at F7, Count 37

00:00:00.001 HDW: ESP8266EX
00:00:00.050 CFG: Loaded from flash at F7, Count 37`

Je viens de commander une D1 en ESP32 en me disant que c'est peut-être un problème de mémoire.
Il me semble être tombé sur un sujet du forum dans lequel la personne avait réussi en tasmota V12 mais plus après. Je pourrais essayer un downgrade. Est-ce une idée ?

ronan-fontenay, 2025-01-08:
Flashé le firmware de @NicolasBernaerts avec succès mais j'ai exactement le même problème.

La configuration se passe bien, mais dès que je coche "standard", je perds toute la conf après le reboot.
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

Je vais attendre l'ESP32 qui arrive vendredi :).
Si d'autres reproduisent le problème, on pourrait peut-être mettre à jour la doc en conseillant fortement l'ESP32 ?

hallard, 2025-01-08:
je le crie à tou va partout :-)

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

ronan-fontenay, 2025-01-08:
Oups la honte, je n'avais pas vu le paragraphe.
Merci d'avoir pris le temps de me répondre, et merci pour ton excellent travail :+1:

NicolasBernaerts, 2025-01-08:
Bonjour,

Vous avez sans doute un WeMos D1 duplicate. Il y a en a beaucoup en circulation. Ils deviennent totalement instables dès qu'ils sont trop chargés.

C'est vrai avec beaucoup de firmwares.

Je ne sais pas pourquoi ...

hallard, 2025-01-08:
Peut être avec un régulateur 3.3V de merde on avait le même soucis avec les brownout a répétition sur les D1 ESP32 aussi

ronan-fontenay, 2025-01-08:
Je vous ferai un retour après passage à l'ESP32 (une AzDelivery depuis leur shop officiel).
Merci pour vos feedbacks ! Je ne voyais pas autant de rebondissements pour un simple changement de mode TIC :)

hallard, 2025-01-08:
> Je ne voyais pas autant de rebondissements pour un simple changement de mode TIC :)

Et moi donc, à ajuster les valeurs de résistances pendant 2 ans pour que ça marche sur tous les compteurs et quand arrive le mode standard qui fou tout par terre ...

ronan-fontenay, 2025-01-18:
Fonctionne parfaitement avec ESP32 👍

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

hallard, 2025-01-18:
Nickel, je te conseille l'excellent firmware de Nicolas :-)

https://github.com/NicolasBernaerts/tasmota/tree/master/teleinfo/binary

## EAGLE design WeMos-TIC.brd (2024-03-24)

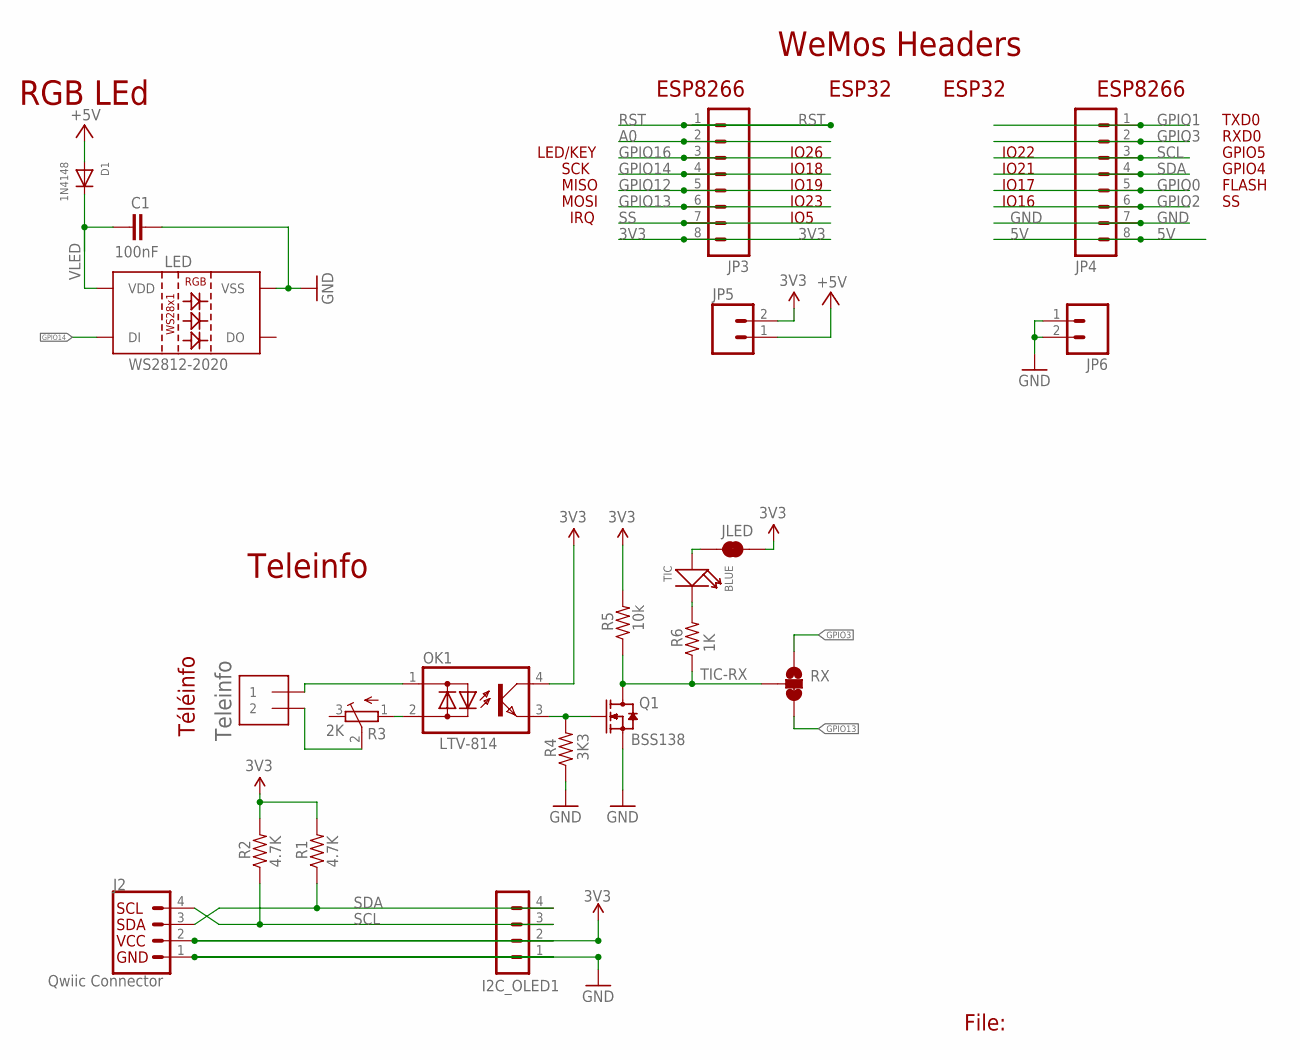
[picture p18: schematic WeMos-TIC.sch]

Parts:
C1: 100nF; 0402-CAP-OK
D1: 1N4148; SOD-523
I2C_OLED1: CON_HEADER_1X04'SMALL''; M1X4
J1: KF2EDGR-3.81-2P; 1X2-3.5MM
J2: Qwiic Connector; JST04_1MM_VERT
JLED: JUMPER-PAD-2-NC_BY_TRACE; PAD-JUMPER-2-NC_BY_TRACE_YES_SILK
JP3, JP4: M08NO_SILK_FEMALE_PTH; 1X08_NO_SILK
JP5, JP6: M021X02_NO_SILK; 1X02_NO_SILK
LED: WS2812-2020
OK1: LTV-814; DIL4-SMD
Q1: BSS138; SOT-323-3
R1, R2: 4.7K; 0402-RES
R3: 2K; TC33X
R4: 3K3; 0402-RES
R5: 10k; 0402-RES
R6: 1K; 0402-RES
RX: TIC-RX; SMT-JUMPER_3_1-NC_TRACE_SILK
TIC: BLUE; LED-0402

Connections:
3V3: I2C_OLED1.2, J2.2, JLED.1, JP3.8, JP5.2, OK1.4 (C), R1.2, R2.2, R5.2
5V: D1.A, JP4.8, JP5.1
A0: JP3.2
GND: C1.1, I2C_OLED1.1, J2.1, JP4.7, JP6.1, JP6.2, LED.2 (VSS), Q1.2 (S), R4.1
GPIO0: JP4.5
GPIO1: JP4.1
GPIO2: JP4.6
GPIO3: JP4.2, RX.1
GPIO12: JP3.5
GPIO13: JP3.6, RX.3
GPIO14: JP3.4, LED.3 (DI)
GPIO16: JP3.3
LTIC: JLED.2, TIC.+
unnamed: R6.2, TIC.-
unnamed: OK1.3 (E), Q1.1 (G), R4.2
unnamed: OK1.2 (AC2), R3.1 (A)
unnamed: J1.1, OK1.1 (AC1)
unnamed: J1.2, R3.2 (S)
RST: JP3.1
SCL: I2C_OLED1.3, J2.4, JP4.3, R2.1
SDA: I2C_OLED1.4, J2.3, JP4.4, R1.1
SS: JP3.7
TIC-RX: Q1.3 (D), R5.1, R6.1, RX.2
VLED: C1.2, D1.K (C), LED.4 (VDD)

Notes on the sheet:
File:
FLASH
MISO
GPIO4
GPIO5
RXD0
TXD0
MOSI
SCK
IRQ
LED/KEY
Teleinfo
WeMos Headers
RGB LEd
ESP32
ESP8266
IO26
IO18
IO19
IO23
IO5
IO16
IO17
IO21
IO22
Téléinfo

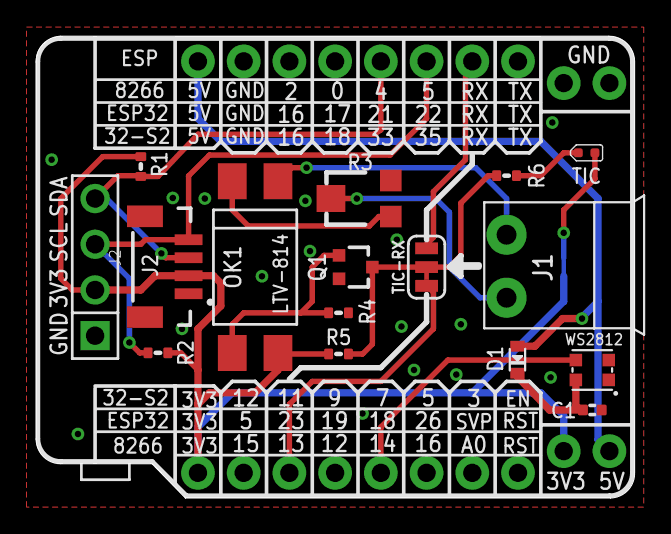
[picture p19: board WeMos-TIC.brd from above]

Board: 2 copper layers, 33.2 x 25.7 mm, 21 parts (1 on the bottom side), 16 nets.

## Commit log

2021-10-29 Bump to V1.1
    [WeMos-TIC.brd, WeMos-TIC.sch]
2021-11-28 Added detailed pinout
    [WeMos-TIC.sch]
2021-12-14 fix ESP32 Rx GPIO
2022-03-18 adding STL file for 3d pronted enclosure
    [enclosure.stl, lid.stl]
2022-03-19 added enclosure link and pictures
2022-05-15 added ESP32 S2
2022-05-15 added ESP32 C3
2024-03-24 Bump to v1.2
    [WeMos-TIC.brd, WeMos-TIC.sch]
2024-03-24 added v1.2 schematics
    added v1.2 schematics
2026-04-29 Switch to CC BY-NC-SA 4.0 license, add LICENSE file

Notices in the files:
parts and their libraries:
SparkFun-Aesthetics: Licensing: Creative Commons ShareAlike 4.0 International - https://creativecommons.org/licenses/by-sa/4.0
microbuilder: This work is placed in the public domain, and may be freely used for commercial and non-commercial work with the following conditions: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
